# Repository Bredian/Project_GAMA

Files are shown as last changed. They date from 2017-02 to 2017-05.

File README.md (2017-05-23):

# Project_GAMA

We are making 8-bit game system on AVR.

Roles on this project as follows:

Gruzdev Fedor - SID chip programming (asm) and general hardware design - Attiny45

Krylov Alexander - Main Processing Unit programming (C lang (+asm maybe)) - Atmega (model unknown for now)

Savostenok Zlata - Controller interface programming (C lang) - Attiny45 + 7400 series logic

Buchnev Arseniy - Hardware maintenance and soldering

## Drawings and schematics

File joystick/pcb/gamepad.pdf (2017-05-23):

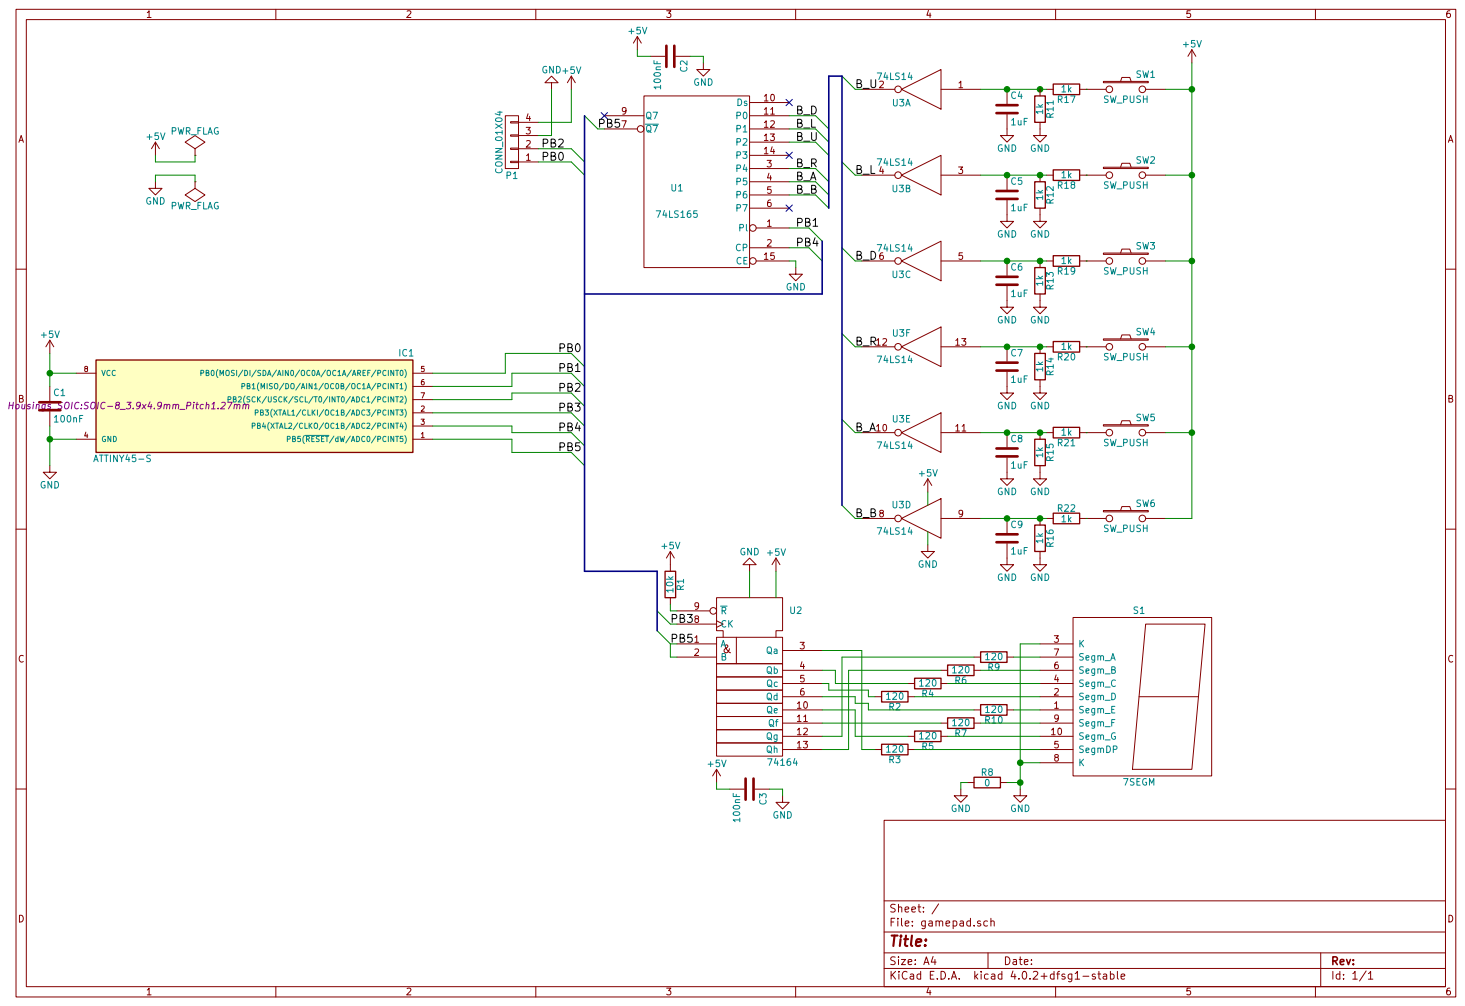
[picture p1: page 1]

GND R12 1k GND R13 1k GND R14 1k GND R15 1k GND R16 1k GND R11 1k

File: gamepad.sch Sheet: /

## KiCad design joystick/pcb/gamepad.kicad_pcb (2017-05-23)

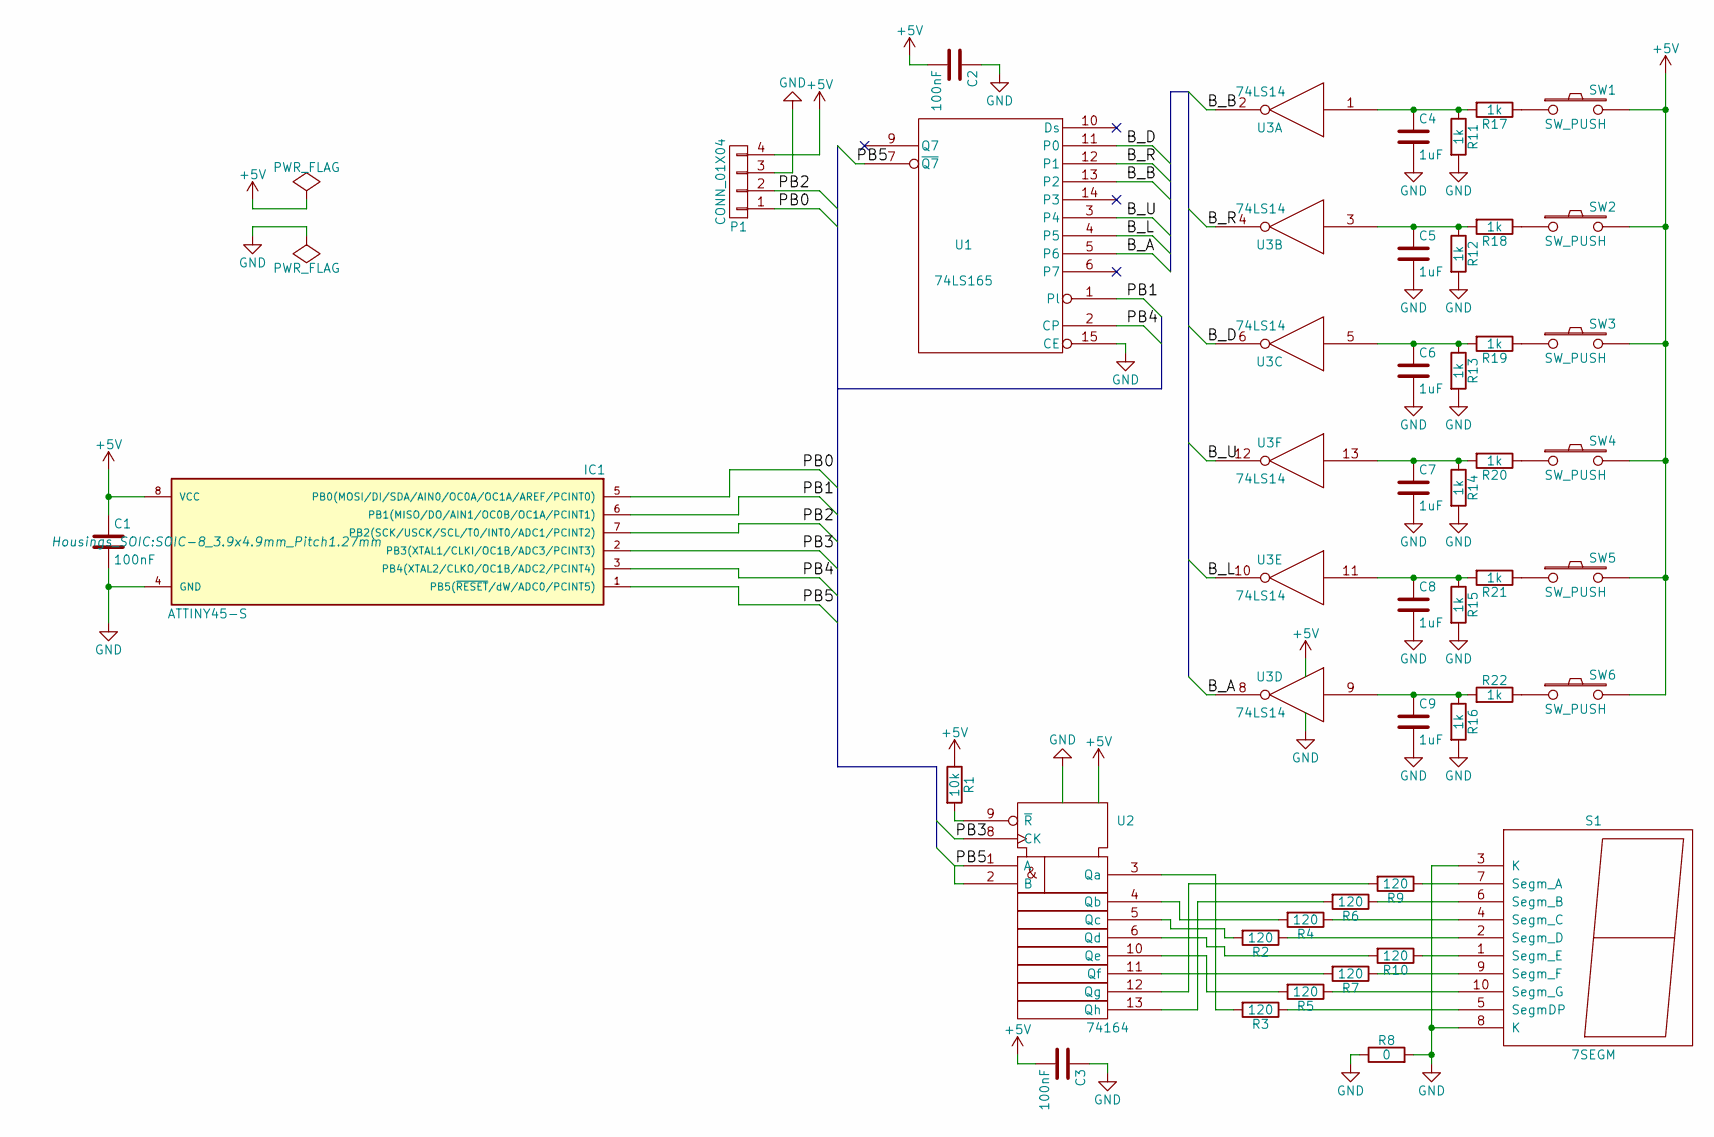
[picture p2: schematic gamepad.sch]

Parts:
C1, C2, C3: 100nF; C_0805_HandSoldering
C4, C5, C6, C7, C8, C9: 1uF; C_0805_HandSoldering
IC1: ATTINY45-S; SOIC-8_3.9x4.9mm_Pitch1.27mm
P1: CONN_01X04; Pin_Header_Angled_1x04
R1: 10k; R_0805_HandSoldering
R2, R3, R4, R5, R6, R7, R9, R10: 120; R_0805_HandSoldering
R8: 0; R_0805_HandSoldering
R11, R12, R13, R14, R15, R16, R17, R18, R19, R20, R21, R22: 1k; R_0805_HandSoldering
S1: 7SEGM; 7SegmentLED_LTS6760_LTS6780
SW1, SW2, SW3, SW4, SW5, SW6: SW_PUSH; SW_PUSH_SMALL
U1: 74LS165; SO-16-N
U2: 74164; SOIC-14_3.9x8.7mm_Pitch1.27mm
U3: 74LS14; SOIC-14_3.9x8.7mm_Pitch1.27mm

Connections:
+5V: C1.1, C2.2, C3.2, IC1.8 (VCC), P1.4, R1.1, SW1.2, SW2.2, SW3.2, SW4.2, SW5.2, SW6.2, U1.16 (VCC), U2.14 (Vdd), U3.14 (VCC)
/B_A: U1.5 (P6), U3.8
/B_B: U1.13 (P2), U3.2
/B_D: U1.11 (P0), U3.6
/B_L: U1.4 (P5), U3.10
/B_R: U1.12 (P1), U3.4
/B_U: U1.3 (P4), U3.12
/PB0: IC1.5 (PB0(MOSI/DI/SDA/AIN0/OC0A/OC1A/AREF/PCI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), P1.1
/PB1: IC1.6 (PB1(MISO/DO/AIN1/OC0B/OC1A/PCINT1)), U1.1 (Pl)
/PB2: IC1.7 (PB2(SCK/USCK/SCL/T0/INT0/ADC1/PCINT2)), P1.2
/PB3: IC1.2 (PB3(XTAL1/CLKI/OC1B/ADC3/PCINT3)), U2.8 (CK)
/PB4: IC1.3 (PB4(XTAL2/CLKO/OC1B/ADC2/PCINT4)), U1.2 (CP)
/PB5: IC1.1 (PB5(~RESET~/dW/ADC0/PCINT5)), U1.7 (~Q7), U2.1 (A), U2.2 (B)
GND: C1.2, C2.1, C3.1, C4.2, C5.2, C6.2, C7.2, C8.2, C9.2, IC1.4 (GND), P1.3, R8.1, R8.2, R11.2, R12.2, R13.2, R14.2, R15.2, R16.2, S1.3 (K), S1.8 (K), U1.8 (GND), U1.15 (CE), U2.7 (Vss), U3.7 (GND)
unnamed: C4.1, R11.1, R17.2, U3.1
unnamed: C5.1, R12.1, R18.2, U3.3
unnamed: C6.1, R13.1, R19.2, U3.5
unnamed: C7.1, R14.1, R20.2, U3.13
unnamed: C8.1, R15.1, R21.2, U3.11
unnamed: C9.1, R16.1, R22.2, U3.9
unnamed: R1.2, U2.9 (~R)
unnamed: R2.1, S1.2 (Segm_D)
unnamed: R2.2, U2.5 (Qc)
unnamed: R3.1, S1.5 (SegmDP)
unnamed: R3.2, U2.3 (Qa)
unnamed: R4.1, S1.4 (Segm_C)
unnamed: R4.2, U2.4 (Qb)
unnamed: R5.1, S1.10 (Segm_G)
unnamed: R5.2, U2.10 (Qe)
unnamed: R6.1, S1.6 (Segm_B)
unnamed: R6.2, U2.13 (Qh)
unnamed: R7.1, S1.9 (Segm_F)
unnamed: R7.2, U2.11 (Qf)
unnamed: R9.1, S1.7 (Segm_A)
unnamed: R9.2, U2.12 (Qg)
unnamed: R10.1, S1.1 (Segm_E)
unnamed: R10.2, U2.6 (Qd)
unnamed: R17.1, SW1.1
unnamed: R18.1, SW2.1
unnamed: R19.1, SW3.1
unnamed: R20.1, SW4.1
unnamed: R21.1, SW5.1
unnamed: R22.1, SW6.1

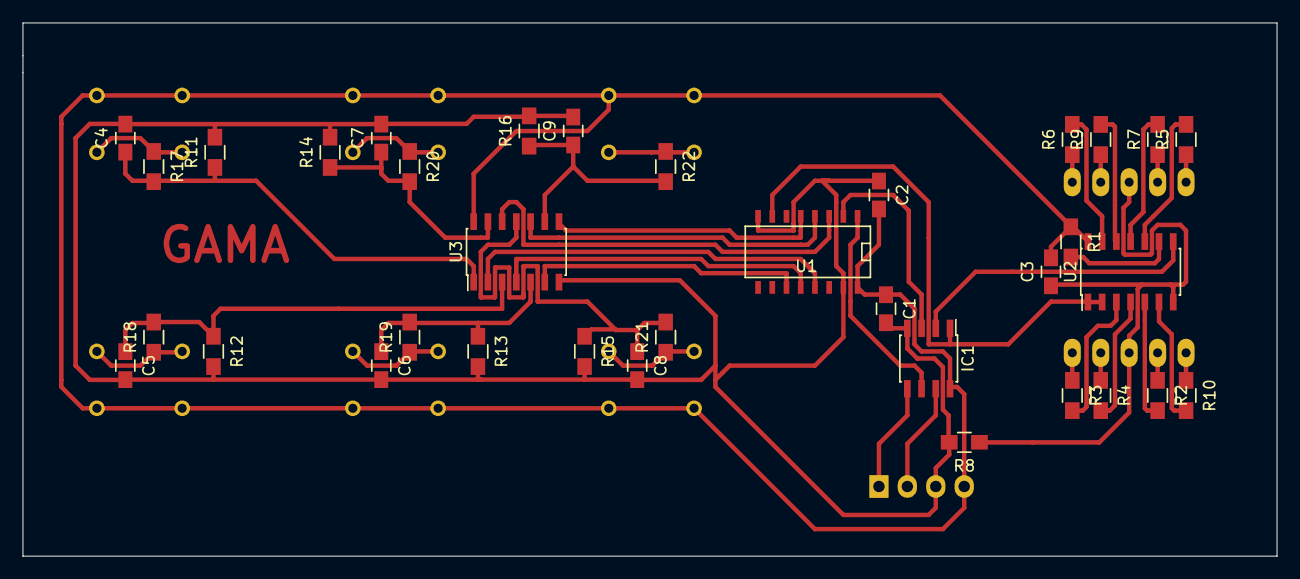
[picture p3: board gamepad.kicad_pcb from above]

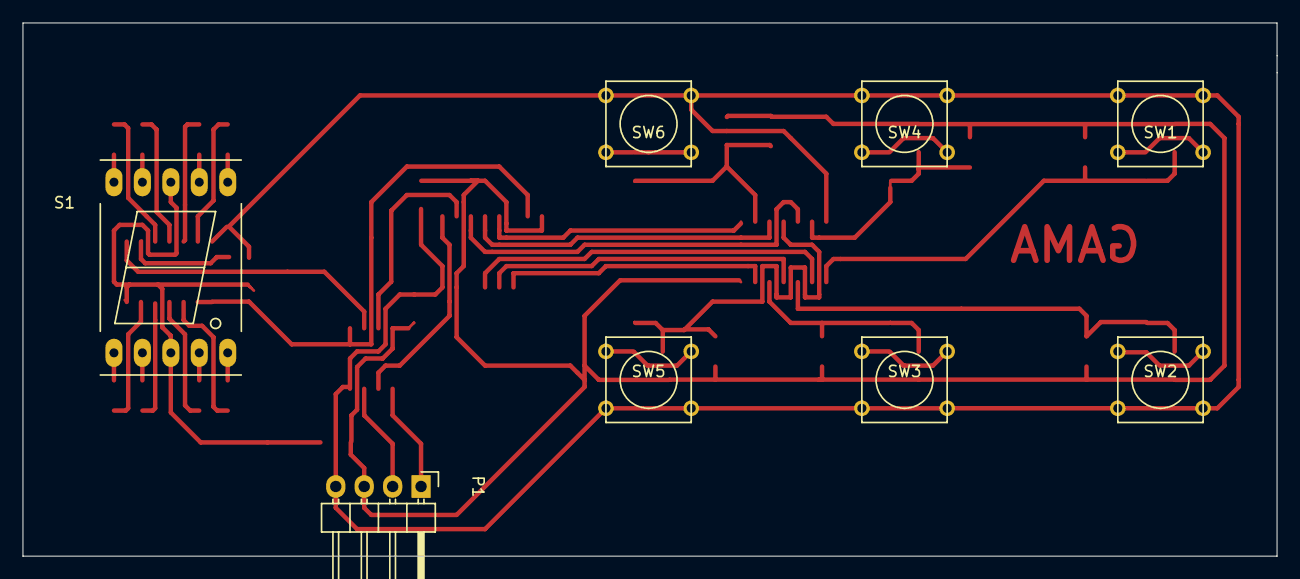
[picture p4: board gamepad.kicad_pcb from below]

Board: 2 copper layers, 112.0 x 47.6 mm, 43 parts (8 on the bottom side), 43 nets.

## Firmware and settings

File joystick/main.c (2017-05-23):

#include <avr/io.h>
#include <avr/interrupt.h>
#include <avr/cpufunc.h>
#include "USI_TWI_Slave.h"

#define SLAVE_ADDR 0x02

#define SAMPLE PB1
#define CLK_7SEG PB3
#define CLK_BUT PB4
#define DATA PB5


void main(void) __attribute__((noreturn));
uint8_t read_buttons(void);
void set_7seg(uint8_t num);


void main(void) {
	
	uint8_t tmp;
	
	DDRB = (1 << SAMPLE)|(1 << CLK_7SEG)|(1 << CLK_BUT)|(0 << DATA);//port directions
	PORTB = (1 << SAMPLE)|(1 << CLK_7SEG)|(1 << CLK_BUT);			//initial port states
	
	USI_TWI_Slave_Initialise(SLAVE_ADDR);
	
	sei();
	
	while(1) {
		
		if(USI_TWI_Data_In_Receive_Buffer())
			{
				tmp = USI_TWI_Receive_Byte();
				set_7seg(tmp);
			}
		
		tmp = read_buttons();
		USI_TWI_Transmit_Byte(tmp);	//not actually transmit, but put in buffer in order to transmit
	}
	
}


uint8_t read_buttons(void) {
	uint8_t buttons = 0, tmp = 0, i;
	
	DDRB &= ~(1 << DATA);			//will receive data
	
	PORTB &= ~(1 << SAMPLE);		//sampling buttons
	_NOP();
	_NOP();
	PORTB |= (1 << SAMPLE);
	
	PORTB &= ~(1 << CLK_BUT);		//clock goes down
	
	i = 0;
	
	while(i < 8) {
		PORTB |= (1 << CLK_BUT);	//clock goes up, data are clocked out of SR
		_NOP();
		_NOP();
		PORTB &= ~(1 << CLK_BUT);	//clock goes down
		
		tmp >>= 1;
		
		if((PORTB & (1 << DATA)) == 1)//getting data
			tmp |= (1 << 7);
		else
			tmp &= ~(1 << 7);
		
		i++;
	}
									//now we have buttons' state in tmp, LSB is P7 of SR
	
										//magic numbers! actually, we shake bits to get them in right places
	buttons |= (tmp & (1 << 5)) << 5;	//up
	buttons |= (tmp & (1 << 7)) << 4;	//down
	buttons |= (tmp & (1 << 6)) << 3;	//left
	buttons |= (tmp & (1 << 3)) << 2;	//right
	buttons |= (tmp & (1 << 2)) << 1;	//A
	buttons |= (tmp & (1 << 1)) << 0;	//B
	
	return buttons; 
}


void set_7seg(uint8_t num) {
	uint8_t tmp = 0;
	uint8_t i;
	
	tmp = (num & (1 << 4)) << 3;		//magic begins; tmp's MSB is dot
										//the only thing left now is number to display
	switch(num & 0b00001111) {					//loads of magic numbers follow. don't worry, it's just numbers to display 
		case 0: tmp = tmp | 0b01110111;
			break;
		case 1: tmp = tmp | 0b01000001;
			break;
		case 2: tmp = tmp | 0b00111011;
			break;
		case 3: tmp = tmp | 0b01101011;
			break;
		case 4: tmp = tmp | 0b01001101;
			break;
		case 5: tmp = tmp | 0b01101110;
			break;
		case 6: tmp = tmp | 0b01111110;
			break;
		case 7: tmp = tmp | 0b01000011;
			break;
		case 8: tmp = tmp | 0b01111111;
			break;
		case 9: tmp = tmp | 0b01101111;
			break;
		case 0x0a: tmp = tmp | 0b01011111;
			break;
		case 0x0b: tmp = tmp | 0b01111100;
			break;
		case 0x0c: tmp = tmp | 0b00110110;
			break;
		case 0x0d: tmp = tmp | 0b01111001;
			break;
		case 0x0e: tmp = tmp | 0b00111110;
			break;
		case 0x0f: tmp = tmp | 0b00011110;
			break;
	}
	
	DDRB |= (1 << DATA);			//now we send data
	for(i = 0; i < 8; i++) {		//shifting data out. LSB goes first
		PORTB &= ~(1 << CLK_7SEG);	//clock goes down
		if ((tmp & 1) == 1) PORTB |= (1 << DATA);
			else PORTB &= ~(1 << DATA);	//putting data bit on DATA
		_NOP();
		_NOP();
		PORTB |= (1 << CLK_7SEG);	//clock goes up, shifting our data bit out
	}
	
	return;
}

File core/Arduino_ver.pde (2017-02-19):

/*Display Inclusion*/
#include <LiquidCrystal.h>
/*For I2C(not relealised in code)*/
#include <Wire.h>
#include <avr/pgmspace.h>
LiquidCrystal lcd(8, 9, 10, 11, 12, 13);

/*bomb variables*/
int bx=-1,by=-1,btimer=0,bp=0,bc=3;
/*tiles*/ 
/*Detail for sceleton Sans*/
byte TL[8] = {
  0b00000,
  0b00011,
  0b00100,
  0b00100,
  0b01000,
  0b01000,
  0b01000,
  0b01000
};
/*Bomb tile*/
byte bomba[8]={
  0b00001,
  0b00011,
  0b00100,
  0b01110,
  0b11111,
  0b11111,
  0b11111,
  0b01110
};
/*Detail for sceleton Sans*/
byte TM[8] = {
  0b00000,
  0b11111,
  0b00000,
  0b11011,
  0b11011,
  0b00000,
  0b00100,
  0b01110
};
/*Wall tile*/
byte wall[8] = {
  0b00000,
  0b00000,
  0b00000,
  0b00100,
  0b01100,
  0b01110,
  0b11110,
  0b11111
};
/*Player tile*/
byte player[8] = {
  0b01110,
  0b01010,
  0b01110,
  0b00100,
  0b01110,
  0b10101,
  0b00100,
  0b11011
};
/*Detail for sceleton Sans*/
byte TR[8] = {
  0b00000,
  0b11000,
  0b00100,
  0b00100,
  0b00010,
  0b00010,
  0b00010,
  0b00010
};
/*Detail for sceleton Sans*/
byte BL[8] = {
  0b00110,
  0b01100,
  0b01000,
  0b01000,
  0b00110,
  0b00001,
  0b00000,
  0b00000
};
/*Detail for sceleton Sans*/
byte BM[8] = {
  0b00000,
  0b11111,
  0b01010,
  0b11111,
  0b00000,
  0b11111,
  0b00000,
  0b00000
};
/*Detail for sceleton Sans*/
byte BR[8] = {
  0b01100,
  0b00110,
  0b00010,
  0b00010,
  0b01100,
  0b10000,
  0b00000,
  0b00000
};

byte gold[8]={
  0b01110,
  0b11111,
  0b11011,
  0b10011,
  0b11011,
  0b10001,
  0b11111,
  0b01110
};

byte omich[8]={
  0b01010,
  0b11111,
  0b11111,
  0b10101,
  0b11011,
  0b00011,
  0b11111,
  0b11111
};
 
/*level, enemies, hero*/
int level=1;
int enemies [80][2];
int herox,heroy;
/*clear map*/
char mapac1[10][42]=
    {   
        {'=','=','=','=','=','=','=','=','=','=','=','=','=','=','=','=','=','=','=','=','=','=','=','=','=','=','=','=','=','=','=','=','=','=','=','=','=','=','=','=','=','='},
        {'=','.','#','.','.','.','.','.','.','.','.','.','.','.','.','#','.','.','.','.','.','.','.','.','#','#','.','.','.','.','.','.','.','.','.','.','.','.','.','.','.','='},
        {'=','.','.','.','#','#','.','.','.','#','#','.','#','#','#','#','#','.','#','#','.','.','.','.','#','#','.','.','.','.','.','.','.','#','.','.','.','.','.','.','.','='},
        {'=','#','.','.','#','.','.','.','.','.','#','.','.','.','.','#','.','.','#','.','.','.','.','.','.','.','.','.','.','.','.','.','.','.','.','.','.','.','.','.','.','='},
        {'=','#','#','.','#','#','#','#','.','.','#','#','.','.','.','.','.','.','.','.','#','.','.','.','#','#','.','.','.','.','.','.','.','.','.','.','.','.','.','.','.','='},
        {'=','#','.','.','.','.','#','.','.','#','.','.','#','#','#','#','#','#','#','#','#','.','.','.','#','#','.','.','.','.','.','.','.','.','.','.','.','.','.','.','.','='},
        {'=','.','#','#','#','#','#','.','#','.','.','.','.','.','.','.','.','.','.','.','#','.','.','.','.','.','.','.','.','.','#','.','.','.','.','.','.','.','.','.','.','='},
        {'=','.','.','.','.','.','.','.','#','.','#','#','#','.','#','.','.','#','#','.','#','.','.','.','#','#','.','.','.','.','.','.','.','.','#','#','#','.','.','.','.','='},
        {'=','.','.','.','.','.','.','.','.','.','#','.','.','.','.','.','#','.','.','.','#','.','.','.','#','#','.','.','.','.','.','.','.','.','.','.','#','.','.','.','.','='},
        {'=','=','=','=','=','=','=','=','=','=','=','=','=','=','=','=','=','=','=','=','=','=','=','=','=','=','=','=','=','=','=','=','=','=','=','=','=','=','=','=','=','='},
    };
/*Main game map*/
char mapa[10][42];
/*some music*/
int mainTheme[]{
  117,0,466, 175,0,466, 233,0,466, 233,175,349, 233,175,349, 233,175,466, 104,0,415, 104,0,370, 104,0,415, 156,0,415, 156,208,415, 93,0,466, 139,0,466, 185,0,466, 185,139,349, 185,139,349, 185,139,466, 87,0,440, 87,0,392, 87,0,440, 131,0,440, 131,175,440
};

int mainDurations[]{
  1200,1200,1200,520,520,520,300,300,300,1200,1200,1200,1200,1200,520,520,520,300,300,300,1200,1200
};

int chords[] = {
  147,0,0,   175,220,0,   175,220,0,   165,0,0,  165,196,247,  175,0,0, 220,262,0, 220,262,0, 165,0,0, 165,196,247, 147,0,294, 147,0,349, 175,220,587, 165,0,294, 165,0,349, 196,247,587, 175,0,659, 220,262,0, 220,262,699, 220,262,659, 220,262,699, 165,0,659, 165,0,523, 196,247,440, 117,0,440, 196,233,294, 196,233,349, 196,233,392, 175,0,440, 175,220,440, 117,0,440, 196,233,294, 196,233,349, 196,233,392, 110,0,330, 165,220,330, 147,0,294, 147,0,349, 175,220,587, 165,0,294, 165,0,349, 196,247,587, 175,0,659, 220,262,0, 220,262,699, 220,262,659, 220,262,699, 165,0,659, 165,0,523, 196,247,440, 117,0,440, 196,233,294, 196,233,349, 196,233,392, 110,0,440, 175,220,440, 147,0,0,   175,220,0,   175,220,0,   165,0,0,  165,196,247,  175,0,0, 220,262,0, 220,262,0, 165,0,0, 165,196,247 
};

int noteDurations[] = {
  480,480,480,480,1200,480,480,480,480,1200,120,120,1200,120,120,1200,480,120,80,80,80,80,80,1200,480,480,120,120,480,1200,480,480,120,120,480,1200,120,120,1200,120,120,1200,480,120,80,80,80,80,80,1200,480,480,120,120,1200,480,480,480,480,480,1200,480,480,480,480,1200
};

/*how to play chords*/

void chord(int pin,int duration, int pitch_1, int pitch_2, int pitch_3){
  int i=0;
  if(pitch_2==0 && pitch_3==0){
    while(i<duration){
    tone(pin,pitch_1,30);
    delay(30);
    noTone(pin);
    tone(pin,pitch_1*1.01,30);
    delay(30);
    noTone(pin);
    i=i+120;
    }
        }
  if(pitch_2!=0 && pitch_3==0){
  while(i<duration){
  tone(pin,pitch_1,30);
  delay(30);
  noTone(pin);
  tone(pin,pitch_2,30);
  delay(30);
  noTone(pin);
  i=i+120;
  }
  delay(120);
  }
  else {
  while(i<duration){
  tone(pin,pitch_1,20);
  delay(20);
  noTone(pin);
  tone(pin,pitch_2,20);
  delay(20);
  noTone(pin);
  tone(pin,pitch_3,20);
  delay(20);
  noTone(pin);
  i=i+120;    
  }
  delay(120);
  }
}

void main_chord(int pin,int duration, int pitch_1, int pitch_2, int pitch_3){
  
  int i=0;
  if(pitch_2==0 && pitch_3==0){
    while(i<duration){
    tone(pin,pitch_1,30);
    delay(30);
    noTone(pin);
    tone(pin,pitch_1*1.01,30);
    delay(30);
    noTone(pin);
    i=i+120;
    return;
    }
        }
  if(pitch_2!=0 && pitch_3==0){
  while(i<duration){
  tone(pin,pitch_1,30);
  delay(30);
  noTone(pin);
  tone(pin,pitch_2,30);
  delay(30);
  noTone(pin);
  i=i+120;
  }
  delay(20);
  return;
  }
  else {
  while(i<duration){
  tone(pin,pitch_1,20);
  delay(20);
  noTone(pin);
  tone(pin,pitch_2,20);
  delay(20);
  noTone(pin);
  tone(pin,pitch_3,20);
  delay(20);
  noTone(pin);
  i=i+120;    
  }
  delay(20);
  return;
  }
}
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

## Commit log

2017-02-19 Create Prototype
2017-03-07 INIT
    Added dirs for every part and current results.
    [gamepad.kicad_pcb, gamepad.sch]
2017-03-13 Updated joystick's circuit
    [gamepad.kicad_pcb, gamepad.sch]
2017-04-03 Fixed hardware bug (74LS14 inputs were left floating) Changed schematics accordingly
    [gamepad.kicad_pcb, gamepad.sch]
2017-04-10 wrote part of TWI logic buffer operations and main interrupt are left also decided on slave address (0x03)
2017-04-12 wrote all TWI (I2C) parts mapped memory
2017-05-03 Started writing firmware. TWI communication - done (code from Atmel AVR312 Application Note). 7 segment - done. buttons - TODO. Makefile - TODO.
    [gamepad.kicad_pcb, gamepad.sch]
2017-05-04 finished firmware small fix in pcb to get buttons in right order TODO: Makefile
    [gamepad.kicad_pcb, gamepad.sch]
2017-05-23 tried to fix joystick's firmware
    [main.c]
2017-05-23 tried to fix core's firmware
    [i2c.c, lcdconf.h]
2017-05-23 getting ready to merge with joystick
    [gamepad.kicad_pcb, gamepad.sch]
